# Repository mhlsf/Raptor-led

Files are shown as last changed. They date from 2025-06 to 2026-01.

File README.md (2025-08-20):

<p align="center">
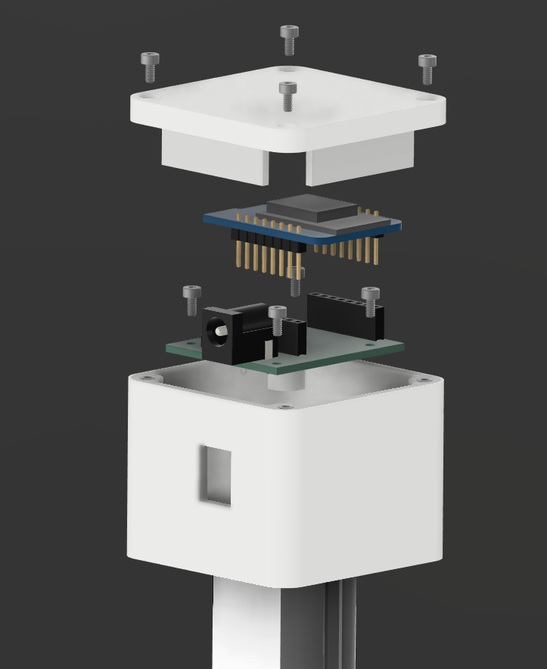
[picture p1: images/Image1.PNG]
 
</p>

# Welcome to the project of open source pixel bar !

The project goal is to create an Astera like Pixel bar, that is easy to build and cheap !

It work around Wemos D1 esp8266 and feature a custom shield and enclosure to plug on a aluminium profile. We are using [Wled library](https://github.com/wled/WLED) to run the project !

**If you are not interested on the technical side of the project, you can buy a kit with all the component needed to make yours in under 1 hours !** You can send me a message to **mahel.sif+led@gmail.com** for price details

## List of components

- Wemos D1 microcontroller [Aliexpress](https://fr.aliexpress.com/item/1005007877904928.html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)
- 8 x 3D printing insert M2, OD3.5 lenght 3mm [Aliexpress](https://fr.aliexpress.com/item/1005003582355741.html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)
- 8 x M2 4mm long Screw [Aliexpress](https://fr.aliexpress.com/item/32810872544.html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)
- WS2812B eco led strip 1M, 60 leds IP65
- Led Aluminium profile (See section below)
- Custom Shield (See section below)
- 3D print box (See section below)

### Led Aluminium profile

The led aluminiun profile should have the following shape and be 1 meter long :



<br/>

They often provide a screw for each side to attach the enclosure.

It can be found on Amazon, but if you send me message I may get them for you cheaper as I order in bulk ! 

### Custom shield for Wemos D1

<p align="center">
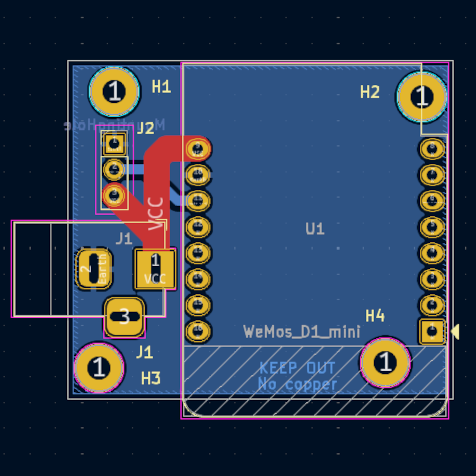
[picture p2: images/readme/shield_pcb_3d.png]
 
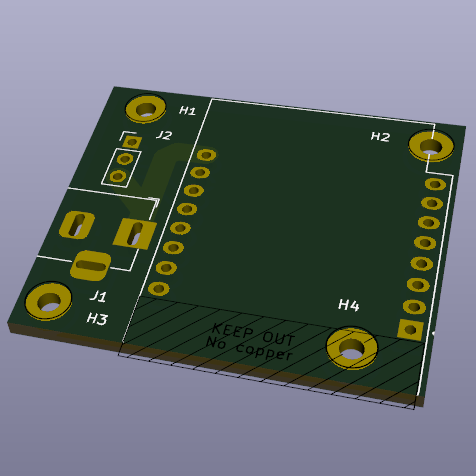
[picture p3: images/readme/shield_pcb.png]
 
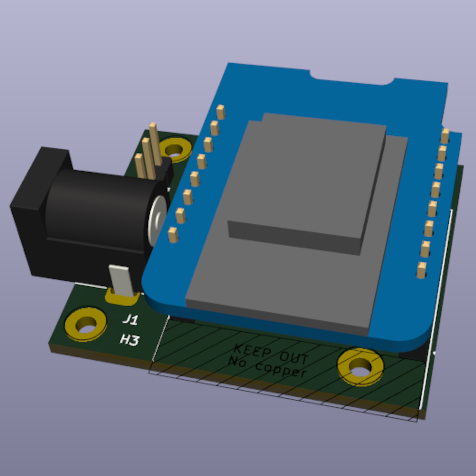
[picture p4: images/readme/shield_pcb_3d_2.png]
 
</p>

The shield consist of a simple PCB that route power from the a Barrel jack input to the Wemos D1 and to the led strip with a jst connector.

The shield can be ordered online (JLCPCB for example), you then need to solder :

- Barrel Type DC Connector  [Aliexpress](https://www.aliexpress.com/item/4001206395694.html?spm=a2g0o.order_list.order_list_main.89.571b1802pOpXx)
- 2.54mm pin connector
- Female 8 Pin Header Socket

The 4 mounting Hole H1-H4 are for mounting to the 3D Print case

The kicad project with PCB layout and schematic is available as a zip named [Wemos D1 shield.zip](https://github.com/mhlsf/Raptor-led/blob/main/Wemos%20d1%20shield.zip)

If needed, contact me, I can send you the ready to plug PCB for a small price !

### 3D print box

The box can be printed using any recent 3D printer. It features holes for M3 inserts to screw the PCB and the lid. STEP files are available [here](https://github.com/mhlsf/Raptor-led/tree/main/stl).

There is three stl, one for the box for PCB, one for the lid of the box and one for the other end of the led bar.

8 holes for M3 insert are made for fixing the PCB board and the lid.

At the bottom of the PCB box, there is a hole for passing led cable and to fix the box to the bar using a small screw.

<p align="center">
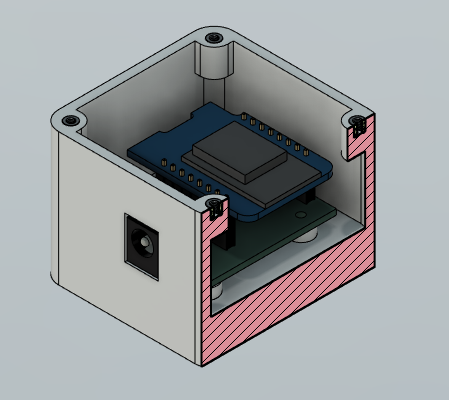
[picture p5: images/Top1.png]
 
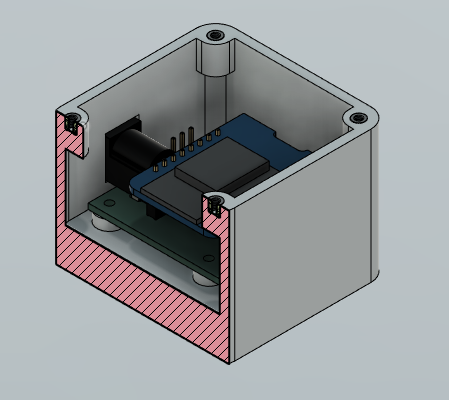
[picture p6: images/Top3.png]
 
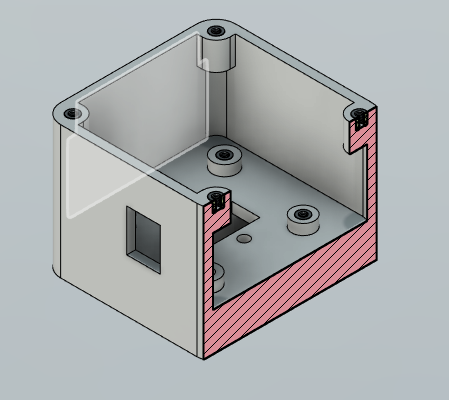
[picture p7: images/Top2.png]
 
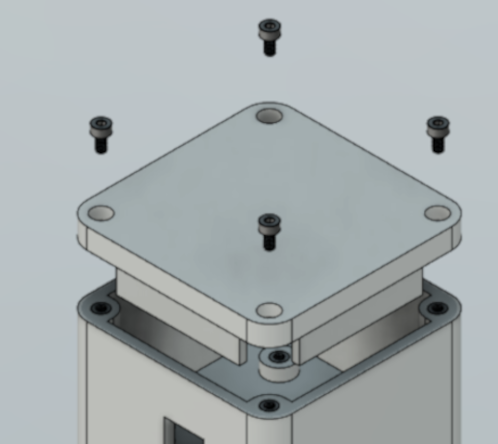
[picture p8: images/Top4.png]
 
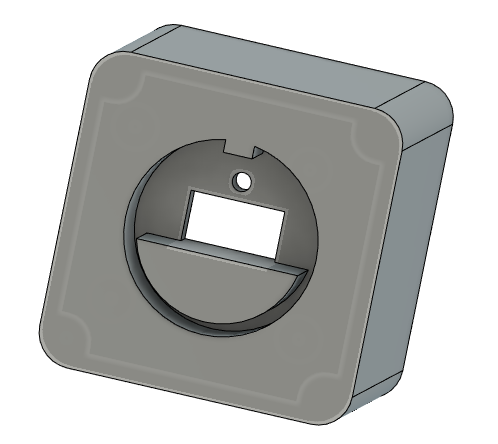
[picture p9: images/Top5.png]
 
</p>

## Power 

Connect any 5V power source to the input jack and you are good to go.

#### Portable :

Most of the time I use [this cable](https://www.aliexpress.com/item/1005004886885121.html?spm=a2g0o.order_list.order_list_main.17.24f05e5b1uxWho) (you need the 5.5mm x 2.1mm version) and plug them directly to a portable battery.

On one 10 000mah portable battery, I can run two bar for around 6 hours at max brightness (depends on the effect used).

#### Fixed :

You can also buy a [5V 60A alimentation](https://www.amazon.fr/Alitove-dalimentation-WS2811-WS2812B-WS2813/dp/B08T2724SD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) to run multiple bar on one power supply.

Be carefull of the wire gauge and the wiring.

## Control

The leds can be controlled through Art-net with software like Resolume, QLC and other lighthing software.

You can also control them using the WLED app, you can check on their website more information about this. 

Many effect are programmed on those and thus easier to setup than a dedicated software.

## What's next ?

My goal is to keep improving on this design, here some of my next iteration : 

- Included Battery
- Accepting range of 5v to 36v
- Tools to quickly discover them on a network, change Wifi Hotspot etc
- Water resistance
- 3D printed Tools to attach them to various support
- Make video tutorial

<br/><br>

## Licence

Shield: [][cc-by-nc-sa]

This work is licensed under a
[Creative Commons Attribution-NonCommercial-ShareAlike 4.0 International License][cc-by-nc-sa].

[][cc-by-nc-sa]

[cc-by-nc-sa]: http://creativecommons.org/licenses/by-nc-sa/4.0/
[cc-by-nc-sa-image]: https://licensebuttons.net/l/by-nc-sa/4.0/88x31.png
[cc-by-nc-sa-shield]: https://img.shields.io/badge/License-CC%20BY--NC--SA%204.0-lightgrey.svg

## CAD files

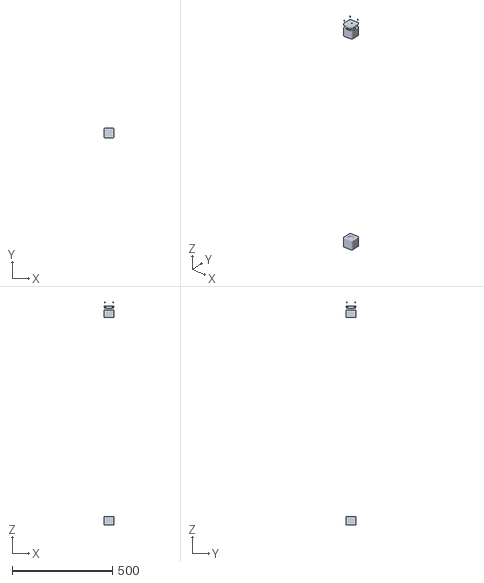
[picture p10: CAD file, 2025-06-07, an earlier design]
stl/Top base.stl
50.0 x 50.0 x 1112.1

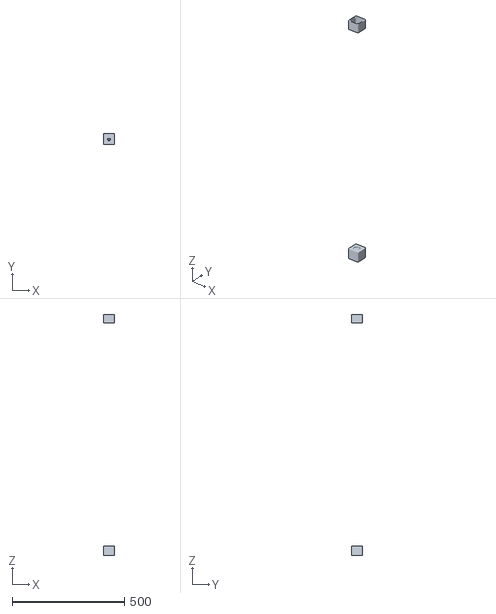
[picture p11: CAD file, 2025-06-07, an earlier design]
stl/Bottom.stl
50.0 x 50.0 x 1073.0

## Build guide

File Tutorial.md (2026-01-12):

# Step by step Guide to build one bar

Depending on the kit you have, you may require the following tool : 

## List of tools
- Solder Iron
- Screwdriver for Allen M2
- Screwdriver for small Cross

## List of components

- Wemos D1 microcontroller [Aliexpress](https://s.click.aliexpress.com/e/_c4cnO3hB)
- 8 x 3D printing insert M3, 3.5mm X 3.5mm [Aliexpress](https://s.click.aliexpress.com/e/_c2wnPTrL)
- 8 x M2 4mm long Screw [Aliexpress](https://s.click.aliexpress.com/e/_c3h62yXP)
- WS2812B eco led strip 1M, 60 leds IP65
- Led Aluminium profile
- Custom Shield
- 3D printed box

<br/><br>

# Step 1

<p align="center">
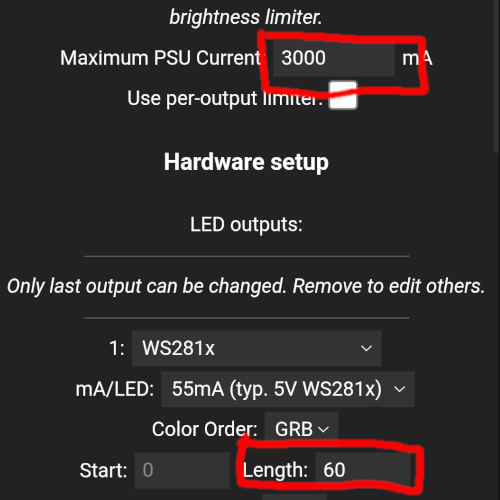
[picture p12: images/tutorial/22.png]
 
</p>

Install wled on the Wemos using this page : https://install.wled.me/ (only work on chrome)

Connect to the router you are going to use for synchronising your led

And then on the setting set the current to 3000ma and the length to 60

# Step 2

<p align="center">
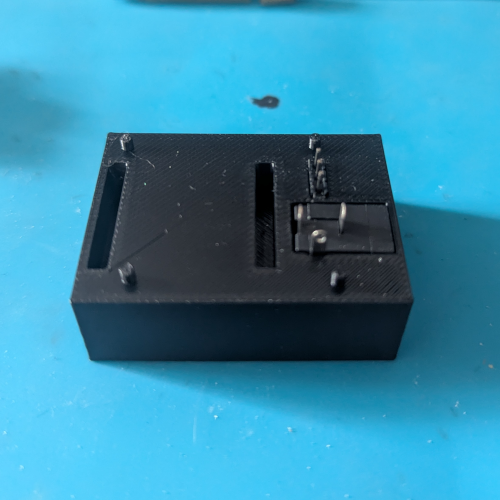
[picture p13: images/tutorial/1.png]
 
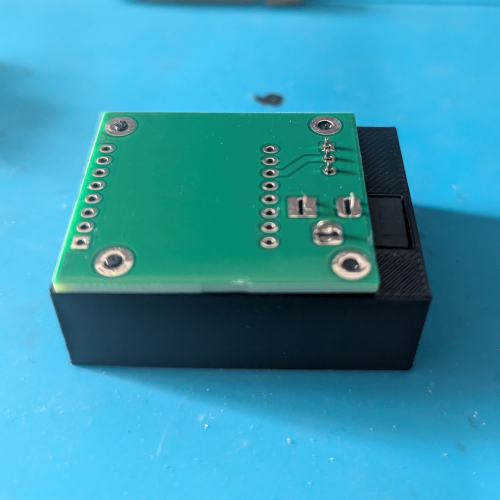
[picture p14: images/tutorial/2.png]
 
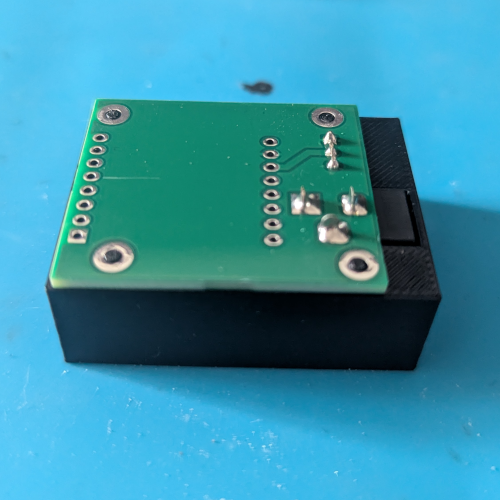
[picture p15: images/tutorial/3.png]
 
</p>

- Pin 2.54mm : [Aliexpress](https://s.click.aliexpress.com/e/_c4cRkKOH)
- Barrel Type DC Connector : [Aliexpress](https://s.click.aliexpress.com/e/_c32rjzPT)

<b> If you received the kit from me you can pass this step.</b>

Solder the pin 2.54mm and the barrel jack to the bare PCB shield, you can use the 3D print guide for better alignement

# Step 3

<p align="center">
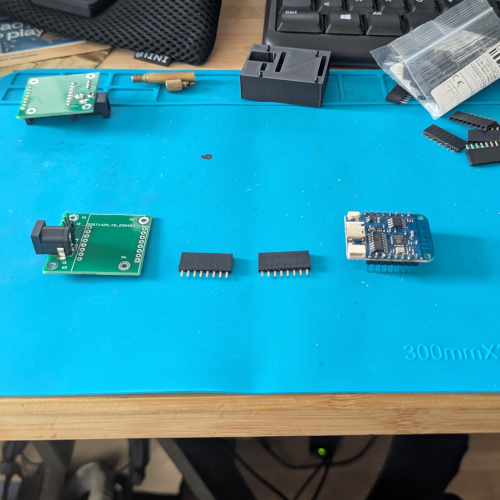
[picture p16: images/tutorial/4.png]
 
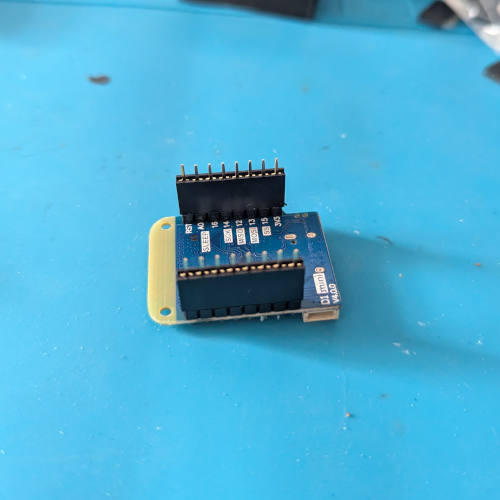
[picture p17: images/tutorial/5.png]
 
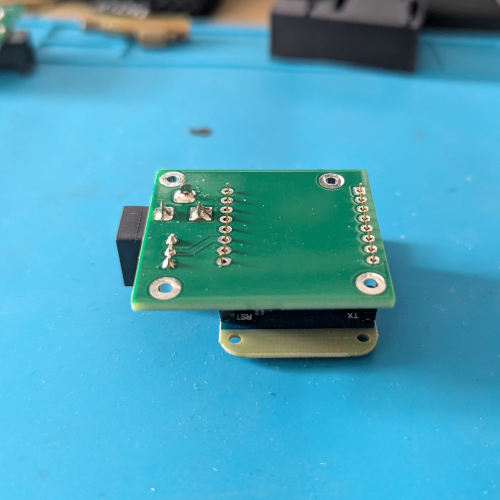
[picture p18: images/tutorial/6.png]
 
</p>

<b> If you received the kit from me you can pass this step.</b>

Solder the receptacle for the Wemos D1 to the shield, you can place the female pin on the wemos to correctly align them when soldering to the shield

# Step 4

<p align="center">
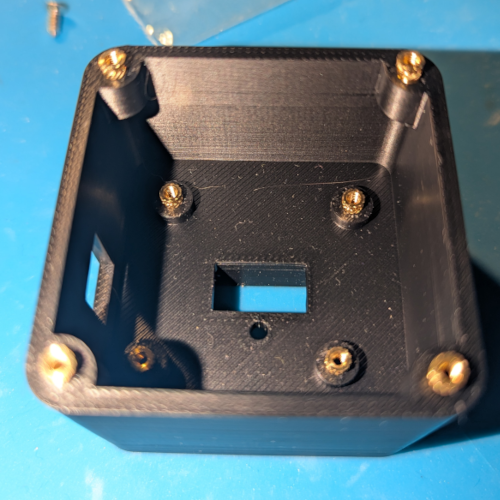
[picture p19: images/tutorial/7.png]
 
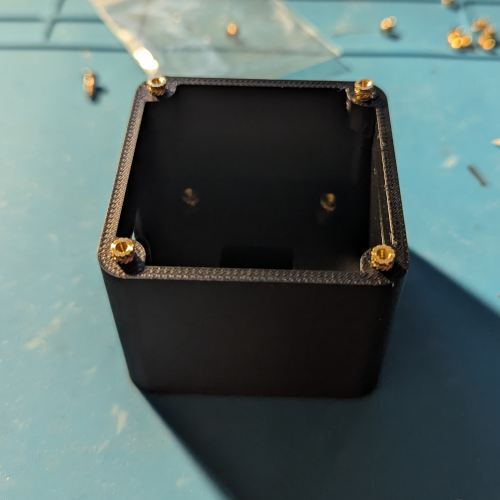
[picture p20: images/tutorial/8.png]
 
</p>
<p align="center">
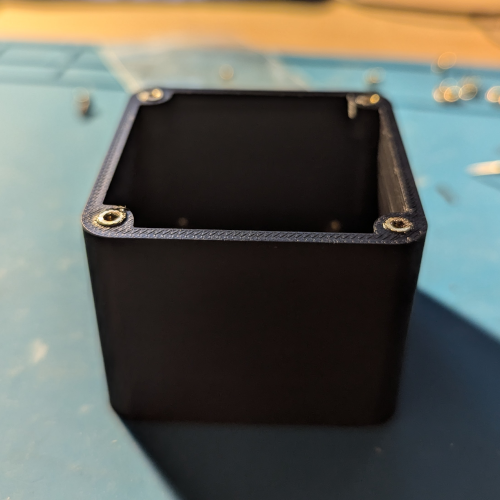
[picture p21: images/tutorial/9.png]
 
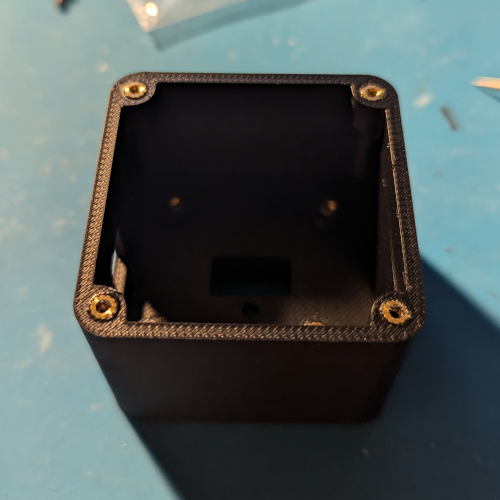
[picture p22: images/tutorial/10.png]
 
</p>

<b> If you received the kit from me you can pass this step.</b>

Place the insert on the 8 holes of the 3D printed part and push them using a soldering iron (Look for tutorial on internet)

# Step 5

<p align="center">
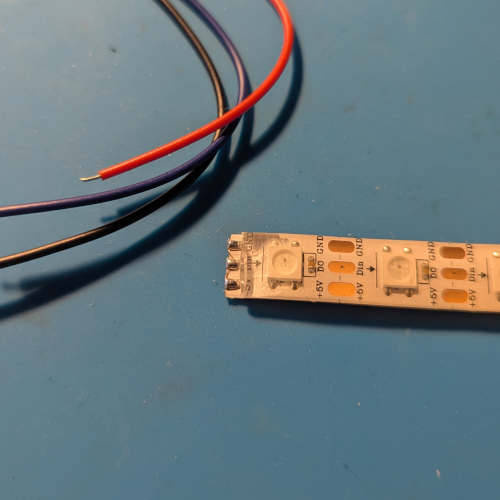
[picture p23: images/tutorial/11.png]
 
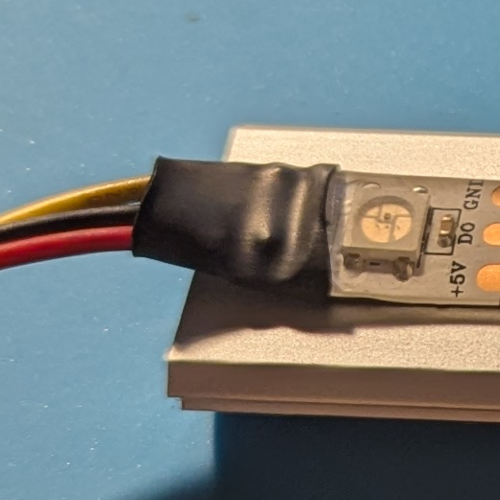
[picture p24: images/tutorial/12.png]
 
</p>

Solder the led connector on the led strip, you can add heat shrink tubing for additionnal protection

Make sure to solder the red cable on the + side etc

# Step 6

<p align="center">
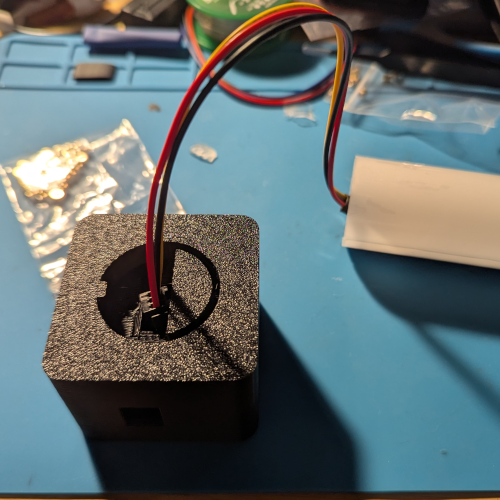
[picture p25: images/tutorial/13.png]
 
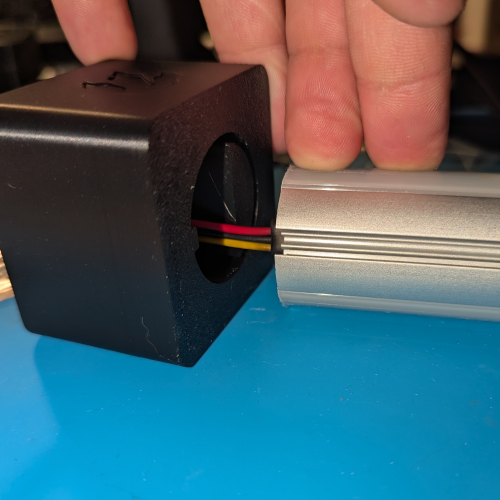
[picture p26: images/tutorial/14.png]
 
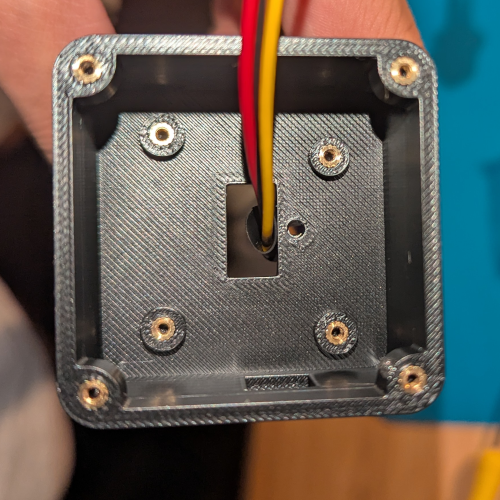
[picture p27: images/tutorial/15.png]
 
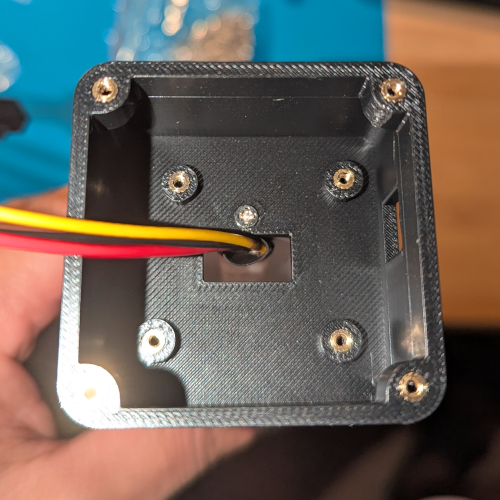
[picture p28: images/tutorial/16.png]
 
</p>

Pass the connector inside the hole on the 3D print part and push the aluminium bar inside while aligning the notch to the hole 

Then put the small screw next to the cable to attach the box and the bar together

# Step 7

<p align="center">
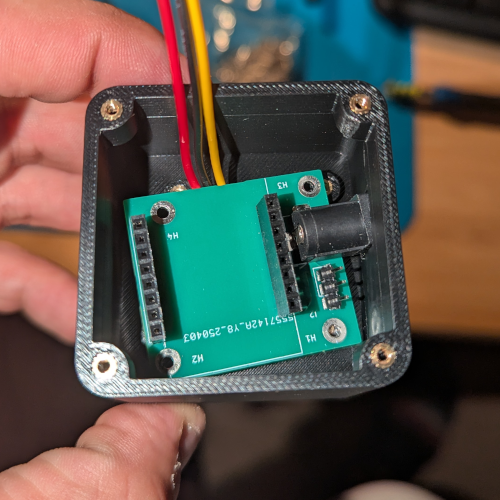
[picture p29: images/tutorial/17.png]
 
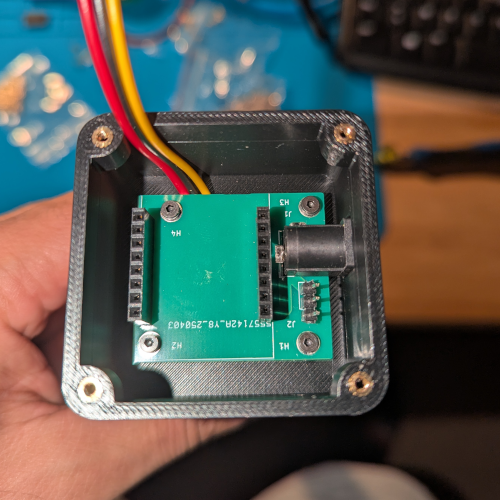
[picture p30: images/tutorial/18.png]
 
</p>

Place the pcb inside the enclosure, make sure to not tangle the cable from the led, the pcb will maintain the cable in place properly

Then you can put the four screw to fix the pcb in place

# Step 8

<p align="center">
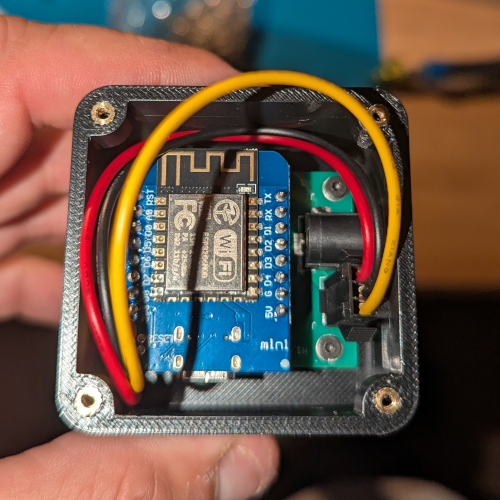
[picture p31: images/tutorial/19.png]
 
</p>

Place the wemos inside on the socket with the 5V pin on the side of the barrel jack

Then place the led connector on the 3 pin headers with the red cable (+ of the led) on the side of the barrel jack

# Step 9

<p align="center">
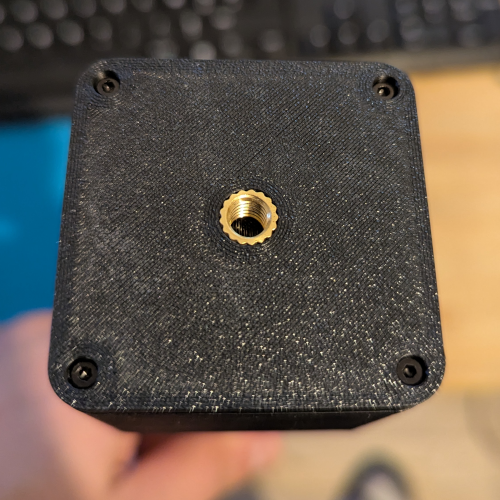
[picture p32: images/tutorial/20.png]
 
</p>

Close the lid for the box and place the four remaining screws

# Step 10

<p align="center">
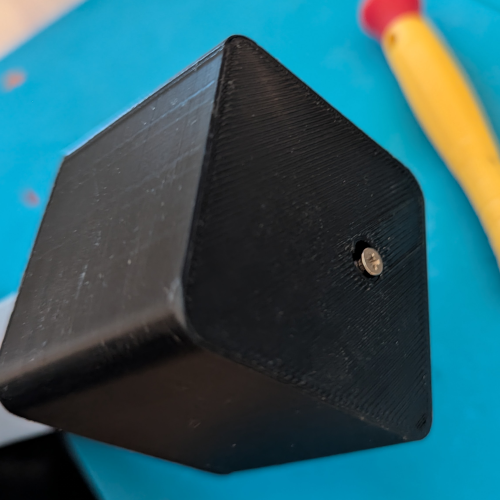
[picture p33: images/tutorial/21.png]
 
</p>

Place the bottom piece on the tip of the bar and screw in the screw

Then you are done ! Enjoy !!!
